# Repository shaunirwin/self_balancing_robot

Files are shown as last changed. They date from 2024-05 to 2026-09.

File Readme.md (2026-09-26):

# Self-balancing robot

Welcome to the project page for the self-balancing robot!

## Objectives

The goal of this project is to develop a robotic platform that can serve as a fun way to explore various aspects of robotics, including classical and learning-based control, 3D vision, sensor fusion and modelling.

## Status

The robot has been built and is currently using PID control for pitch control. Pitch estimation works well. I am busy simulating the system and improving the controller using classical control methods.

Once I am satisfied with the classical controller (both PID and LQR), I will move onto the next phase of learning-based control.

## Project layout

- [Firmware](firmware/platformio_projects/self_balancing_robot/README.md): ESP32 controller, HTTP API, and PC serial reader. Earlier ESP-IDF work is in `firmware/archived/`.
- [Laptop dashboard](software/webserver/README.md): live controls and recording viewer.
- [Python scripts and simulation](software/python/README.md): calibration, plotting, recording conversion, and MuJoCo model.
- [Electronics](electronics/robot_pcb/): KiCad PCB files; [cable harnesses](electronics/cable_harnesses/README.md) are alongside them.
- [Mechanical design](mechanical/Readme.md): Onshape CAD link and printing notes.
- [Recorded data](data/data_logs/README.md): logs and example recordings; older data is in `data/archive/`.
- [Documentation](documentation/): supporting figures.

The robot sitting in its harness:

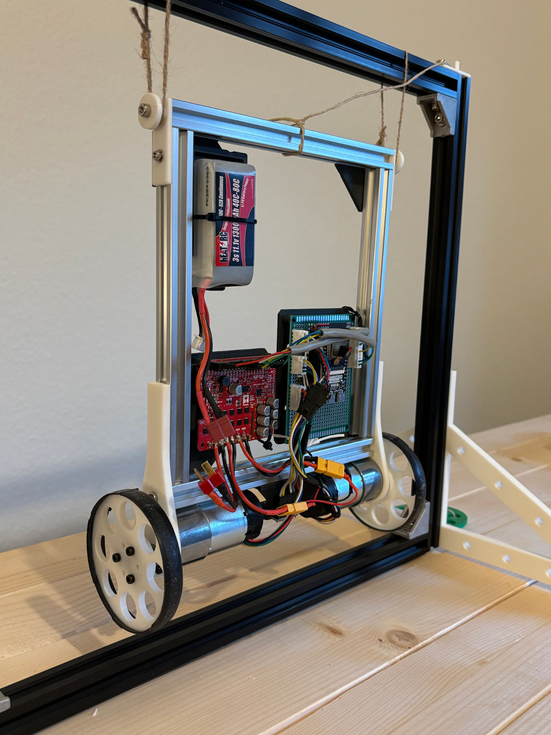
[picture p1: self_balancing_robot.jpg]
Self-balancing robot


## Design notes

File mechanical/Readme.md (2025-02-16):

# Readme

See [here](https://cad.onshape.com/documents/d3fc6fa172b94317767931eb/w/4836ae253482adeaddadde79/e/e547ee002620e145acb73cc3) for the OnShape design files.

I printed all components on a Bambu P1S using PLA.

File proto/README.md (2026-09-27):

# Recording format

`recording.proto` is the shared schema for robot recordings. An `SBRPB1` file
starts with the eight bytes `53 42 52 50 42 31 00 00` (`SBRPB1\0\0`). It is
followed by one varint-length-delimited `RecordingHeader`, then ordered
varint-length-delimited `RecordingBatch` messages until `record_count` samples
have been read. Each batch contains 1–16 samples, and its `first_index` must
equal the number of preceding samples. Files with trailing or missing data are
invalid. No wall-clock time is claimed; sample timestamps are monotonic and
relative to the recording start. Readers limit the header frame to 1024 bytes
and each batch frame to 2048 bytes. The file extension is `.sbrpb`.

The magic and `format_version` identify the framing and semantics. Additive
schema changes may use new field numbers without changing the major file
version. Never reuse a removed field number; mark it `reserved`. Change the
magic and major version if framing or existing field meanings change.

New recordings include `settings_at_start`, captured when the control task
processes Start. Older `SBRPB1` recordings omit it; readers should show
"metadata unavailable" for those and for `SBRLOG1` files. The original
header fields are retained for older protobuf readers. The snapshot holds PID
gains, output limits and integral threshold; pitch setpoint and safety limits;
complementary filter gyro weight; motor speed calibration slopes and intercepts,
direction inversion and coast settings; PWM frequency in Hz and resolution in
bits; wheel diameter in meters and encoder pulses per revolution; and IMU
offsets in radians per second (gyro Y) and radians (accelerometer pitch).
`imu_calibration_valid` is false if calibration had not finished at Start; in
that case the offset numbers are zero placeholders. `firmware_revision` is the
build Git revision, or `unknown` outside a Git checkout.

`settings_changed_during_recording` becomes true when an accepted live tuning
command actually changes a captured tunable value. It stays true if the value
is later restored. It does not track control mode or motor outputs, which are
stored per sample, or the completion of IMU calibration after Start. Thus a
false value means no captured tunable was changed by a command during this
recording; it does not turn the snapshot into a history of settings.

The robot keeps its 32-byte `SBRLOG1` records in RAM and encodes `SBRPB1` only
while downloading. `SBRLOG1` files remain readable by the dashboard and Python
decoder.

The firmware uses nanopb 0.4.9, Python uses generated `recording_pb2.py`, and
the Vite dashboard imports this `.proto` as text for protobuf.js. From the
repository root, run a PlatformIO build once to install nanopb, then regenerate
the checked-in C and Python files after editing the schema:

```sh
cd firmware/platformio_projects/self_balancing_robot
~/.platformio/penv/bin/pio run
cd ../../..
~/.platformio/penv/bin/python firmware/platformio_projects/self_balancing_robot/.pio/libdeps/esp32-s3-devkitc-1/Nanopb/generator/nanopb_generator.py -I proto -D firmware/platformio_projects/self_balancing_robot/src proto/recording.proto
~/.platformio/penv/bin/python -m grpc_tools.protoc -I proto --python_out=software/python proto/recording.proto
```

The dashboard reads the schema directly, so it has no generated file. Other
languages can generate readers from `recording.proto`; their file reader must
also implement the short framing described above.

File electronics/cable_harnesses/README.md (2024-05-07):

# README

This is the readme for cable harness-making.

## Setup

Install wireviz:

~~~
conda create -n wireviz_env python=3.10
conda activate wireviz_env
pip install wireviz

sudo apt-get install graphviz
~~~

## Generate cable harness diagrams

~~~
wireviz ~/path_to_file.yml
~~~

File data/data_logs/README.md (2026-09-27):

# README

This is the readme file for the data recordings in this folder. It describes what each was recorded for and when.

`balance-recording_11Hz_oscillation.bin`
* Created 2026-09-24
* Description: Recording of balancing attempt, where the robot exhibited a very pronounced ~11Hz oscillation on PID output, gyro, pitch, PWM. Robot falls over after a few seconds.
* Useful for: Debugging why the robot is not yet balancing correctly.

`balance-recording_gyros_noisy_motors_on.sbrpb`
* Created 2026-09-26
* Description: In this case the motors were on and the gyros were very noisy.
* Useful for: Investigating noisiness in the gyros. 

`balance-recording_gyros_smooth_motors_off.sbrpb`
* Created 2026-09-26
* Description: In this case the motors were off and the gyros were very smooth.
* Useful for: Investigating noisiness in the gyros.

`20260927-003031_recording_manual_step_motor1_to_35pwm.sbrpb`
* Description: Manual mode. Step input from zero pwm to 35. Gyro readings noisy despite feedback loop being off.
* Useful for: Investigating noisiness in the gyros.

`20260927-003253_recording_manual_step_motor1_to_150pwm.sbrpb`
* Description: Manual mode. Step input from zero pwm to 150. Gyro readings noisy despite feedback loop being off.
* Useful for: Investigating noisiness in the gyros.

`20260927-005004_recording_manual_step_motor2_to_35pwm.sbrpb`
* Description: Manual mode. Step input from zero pwm to 35. Gyro readings noisy despite feedback loop being off.
* Useful for: Investigating noisiness in the gyros.

`20260927-005226_recording_manual_step_motor2_to_150pwm.sbrpb`
* Description: Manual mode. Step input from zero pwm to 150. Gyro readings noisy despite feedback loop being off.
* Useful for: Investigating noisiness in the gyros.

`20260927-010502_recording_11hz_oscillation_auto_mode_150hz_sampling.sbrpb`
* Description: Recreated the same experiment as recorded in `balance-recording_11Hz_oscillation.bin`, which was previously done with 100Hz sampling rate. Still same 11Hz oscillation seen when using the 150Hz sampling rate.
* Useful for: Debugging balancing

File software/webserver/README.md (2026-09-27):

# Laptop dashboard

The current dashboard uses `index.html`, `main.js`, and Vite. Earlier control
interface experiments are kept in [`archive/`](archive/README.md).

Run from `software/webserver` with Node.js 20.19+ or 22.12+:

```sh
npm install
ROBOT_URL=http://192.168.178.55 npm run dev
```

Open <http://localhost:5173>. Set `ROBOT_URL` to the robot's HTTP origin on your network (no path or trailing slash). The default is `http://192.168.178.55`. Restart Vite after changing it. The server listens only on loopback. Browser API calls use `/api/*`; Vite forwards them to the robot with `/api` removed. The existing ESP32 endpoints are unchanged.

Open a local `SBRPB1` `.sbrpb` or legacy `SBRLOG1` `.bin` file in the recording viewer, or use Start, Stop, then Download & open. The new download uses the shared protobuf schema in `../../proto/recording.proto`. Click a chart or drag the timeline to inspect the corresponding pitch in the 3D view. Drag across a plot to zoom all charts to the same time range. Scroll over a plot to zoom around the pointer; Shift + scroll, middle-button drag, or the toolbar pans. Reset view restores the full recording. The view shows only pitch. With no recording selected, it follows live status polling. Controller values are submitted through `/set-value` as form fields; the dashboard rereads `/status` to confirm queued changes. Automatic mode may remain inactive if the robot's arm conditions are not met.

Expand **Recording settings** in the viewer for the snapshot captured at Start,
its firmware revision, IMU calibration validity, and the live tuning change
flag. Older recordings show "Metadata unavailable". Units and flag semantics
are documented in [`proto/README.md`](../../proto/README.md).

```sh
npm run build
```

The build checks and bundles the dashboard. For connected controls and recording, use `npm run dev` so the API proxy is active; opening `dist/index.html` directly does not provide a robot connection.

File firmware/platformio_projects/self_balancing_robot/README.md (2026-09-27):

# README

This is the README for the Self-Balancing Robot.

## Building the firmware and serial reader

From the repository root, change to the PlatformIO project directory:

```bash
cd firmware/platformio_projects/self_balancing_robot
```

The firmware includes `src/secrets.h` for Wi-Fi credentials. On a fresh
checkout, create it from the tracked template:

```bash
cp src/secrets_template.h src/secrets.h
```

Edit `src/secrets.h` and replace `REPLACE_WITH_YOUR_SSID` and
`REPLACE_WITH_YOUR_PASSWORD` with your network name and password. The project
ignores `secrets.h` so credentials stay out of commits. Keep the template's
variable names unchanged; `src/main.cpp` uses them to connect to Wi-Fi.

Build both the robot firmware and the PC serial reader:

```bash
make
```

The serial reader is written to `.pio/read_serial`.

To build only one component:

```bash
make firmware
make read_serial
```

The firmware can also be built directly with PlatformIO:

```bash
~/.platformio/penv/bin/pio run
```

## Programming the ESP32 board

Plug the USB cable into the **right** USB slot on the ESP32-S3 WROOM Freenove board to program it and to send/receive serial communication, as shown in [this video](https://www.youtube.com/watch?v=VZDCkARFCPk&ab_channel=Freenove).

From the PlatformIO project directory, build and upload the firmware with:

```bash
make upload
```

This uses `/dev/ttyACM0`, as configured in `platformio.ini`.

The equivalent direct PlatformIO command is:

```bash
~/.platformio/penv/bin/pio run --target upload
```

To open PlatformIO's serial monitor after uploading:

```bash
~/.platformio/penv/bin/pio device monitor
```

Press `Ctrl+C` to exit the monitor.

## To receive serial communication

In the terminal:

```bash
tio /dev/ttyACM0
```
Check that this is the correct comm port (see `platformio.ini`).

`Ctrl+t q` to quit.

Build and run the application that reads and displays data from the ESP32:

```bash
make run-reader
```

Close `tio` or PlatformIO's serial monitor first because only one application can use `/dev/ttyACM0` at a time. Press `Ctrl+C` to stop the reader.

## HTTP control and telemetry

The robot connects to the configured Wi-Fi network and serves HTTP on port 80. The examples below use the current robot address:

```bash
ROBOT=http://192.168.178.55
```

The root endpoint is a simple connectivity check:

```bash
curl "$ROBOT/"
```

Read the live controller state and safety flags:

```bash
curl -s "$ROBOT/status" | python3 -m json.tool
```

Important fields include `CONTROL_MODE`, `ESTIMATES_VALID`, `AUTO_ARM_ALLOWED`, `pitch_angle_current`, and the current PWM limits.

### Updating controller values

`/set-value` is a `POST` endpoint requiring `key` and `value` form fields. Changes are queued for the control task. Angle values are in radians; PWM values are integers from 0 to 255.

Examples:

```bash
# Select or disarm the controller mode
curl -X POST --data-urlencode 'key=CONTROL_MODE' \
  --data-urlencode 'value=MANUAL' "$ROBOT/set-value"

curl -X POST --data-urlencode 'key=CONTROL_MODE' \
  --data-urlencode 'value=AUTO' "$ROBOT/set-value"

# PID parameters and setpoint
curl -X POST --data-urlencode 'key=PID_Kp' \
  --data-urlencode 'value=18' "$ROBOT/set-value"
curl -X POST --data-urlencode 'key=PID_Ki' \
  --data-urlencode 'value=0' "$ROBOT/set-value"
curl -X POST --data-urlencode 'key=PID_Kd' \
  --data-urlencode 'value=0.4' "$ROBOT/set-value"
curl -X POST --data-urlencode 'key=PID_setpoint' \
  --data-urlencode 'value=0' "$ROBOT/set-value"

# Motor limits and pitch safety thresholds
curl -X POST --data-urlencode 'key=MOTOR_DUTY_CYCLE_MIN' \
  --data-urlencode 'value=35' "$ROBOT/set-value"
curl -X POST --data-urlencode 'key=MOTOR_DUTY_CYCLE_MAX' \
  --data-urlencode 'value=160' "$ROBOT/set-value"
curl -X POST --data-urlencode 'key=PITCH_ANGLE_ERROR_MAX' \
  --data-urlencode 'value=0.174533' "$ROBOT/set-value"  # 10 degrees
curl -X POST --data-urlencode 'key=PITCH_ANGLE_ERROR_MIN' \
  --data-urlencode 'value=0.003491' "$ROBOT/set-value"  # 0.2 degrees
```

Manual motor commands are available for bench testing with the wheels raised:

```bash
curl -X POST --data-urlencode 'key=MOTOR_1_DIR_MANUAL' \
  --data-urlencode 'value=FORWARD' "$ROBOT/set-value"
curl -X POST --data-urlencode 'key=MOTOR_2_DIR_MANUAL' \
  --data-urlencode 'value=FORWARD' "$ROBOT/set-value"
curl -X POST --data-urlencode 'key=MOTOR_1_DUTY_CYCLE_MANUAL' \
  --data-urlencode 'value=35' "$ROBOT/set-value"
curl -X POST --data-urlencode 'key=MOTOR_2_DUTY_CYCLE_MANUAL' \
  --data-urlencode 'value=35' "$ROBOT/set-value"
```

Emergency stop:

```bash
curl -X POST --data-urlencode 'key=EMERGENCY_STOP' \
  --data-urlencode 'value=1' "$ROBOT/set-value"
```

The network emergency stop is a software request and is not a substitute for a physical motor-power cutoff.

### Recording telemetry in RAM

The firmware stores up to 20 seconds of 150 Hz telemetry in a fixed 96 KB buffer. Each recording contains pitch, gyro rate, PID output, encoder positions, loop timing, PWM, directions, mode, and estimate-validity flags. Serial telemetry remains at 20 Hz on average.

Start a recording while the robot is still in MANUAL. The dashboard sends its local start time automatically. For HTTP clients, send `started_at` to name the protobuf download from the recording start time:

```bash
curl -X POST --data-urlencode "started_at=$(date +%Y%m%d-%H%M%S)" "$ROBOT/recording/start"
```

The resulting protobuf filename is `YYYYMMDD-HHMMSS_recording.sbrpb`. If `started_at` is omitted, the download keeps the generic `balance-recording.sbrpb` name. The ESP32 has no configured wall clock; the timestamp comes from the client that starts the recording.

Check its progress:

```bash
curl -s "$ROBOT/recording/status" | python3 -m json.tool
```

Stop it explicitly:

```bash
curl -X POST "$ROBOT/recording/stop"
```

The recording also stops when the buffer fills or AUTO disarms. Once the status reports `"state": "READY"`, download and decode it:

```bash
curl -OJ "$ROBOT/recording/download?format=protobuf"
../../../software/python/.venv/bin/python ../../../software/python/decode_recording.py YYYYMMDD-HHMMSS_recording.sbrpb
```

The decoder writes a CSV with the same base name as the downloaded recording, which can be plotted or inspected with standard tools. Python scripts can call `recording_reader.read_recording(path)` to read the protobuf metadata and samples directly. The schema is in `../../../proto/recording.proto`. The robot keeps fixed 32-byte records in RAM and encodes protobuf in small batches only during download. The old `/recording/download` endpoint still serves `SBRLOG1` `.bin` files, which the decoder and dashboard can still read. Only one completed recording is retained; starting a new recording overwrites the previous one. Recordings are held in volatile RAM and are lost if the ESP32 resets or loses power.

Protobuf headers also contain a settings snapshot taken when the control task
processes Start, the build Git revision (or `unknown`), and a flag that turns
true if a captured tunable is changed during recording. Calibration offsets
are marked invalid if IMU calibration had not finished at Start. Field units
and flag semantics are listed in `../../../proto/README.md`.

The old `/logs` endpoint is deprecated and returns an error; use the `/recording/*` endpoints instead.

For compatibility, `START_LOGGING` and `STOP_LOGGING` are also accepted as `/set-value` keys, but the dedicated recording endpoints are preferred.

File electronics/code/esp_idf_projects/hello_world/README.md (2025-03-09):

# Readme

# Initial set up of ESP-IDF

```
git clone
git submodule update --init --recursive
```

# Creating a new project using ESP-IDF

```bash
get_idf
idf.py create-project -p . <project_name>
idf.py set-target esp32-s3
idf.py menuconfig
```

# How to build this project

```bash
get_idf
idf.py build
idf.py flash
idf.py fullclean
```

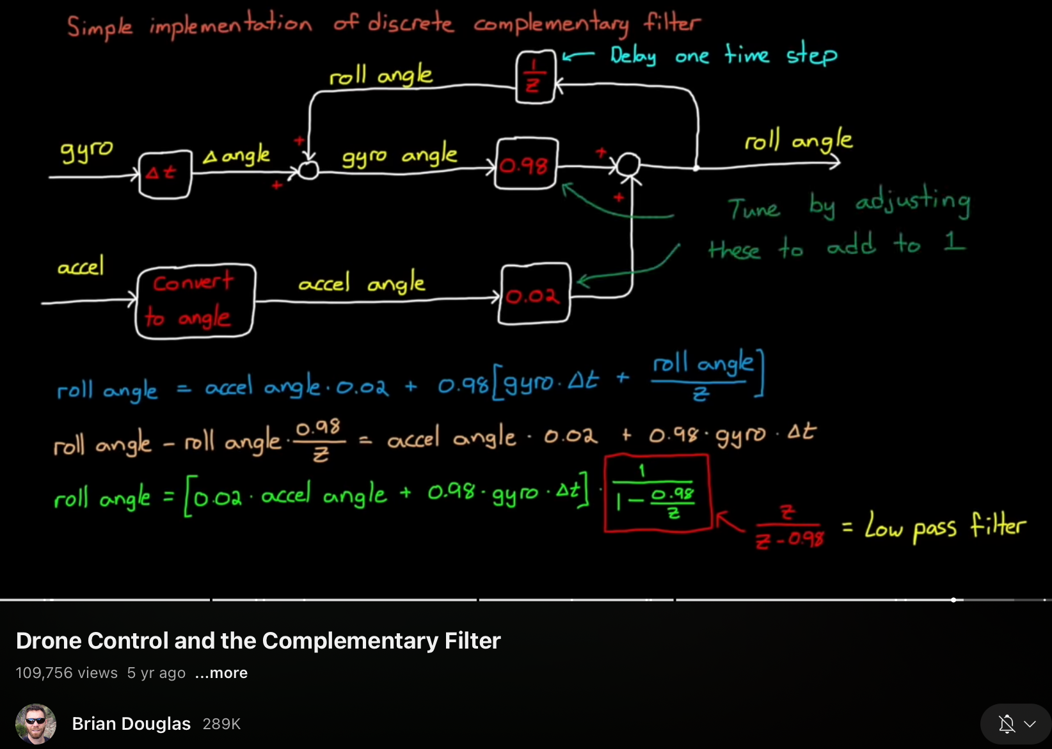
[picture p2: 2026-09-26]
documentation/complementary_filter.jpeg

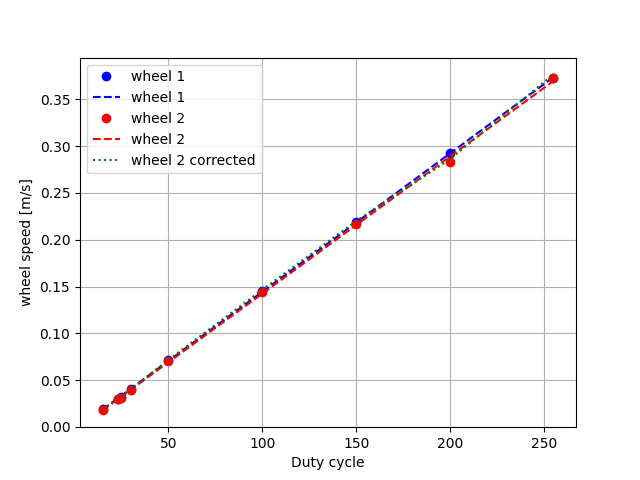
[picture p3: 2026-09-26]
software/python/pwm_calib.png

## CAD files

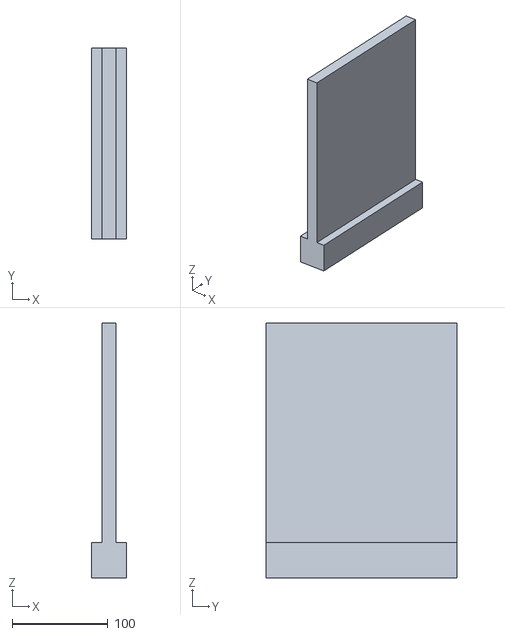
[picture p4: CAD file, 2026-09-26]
software/python/mujoco_simulation/body_v1.stl
37.0 x 200.0 x 267.0

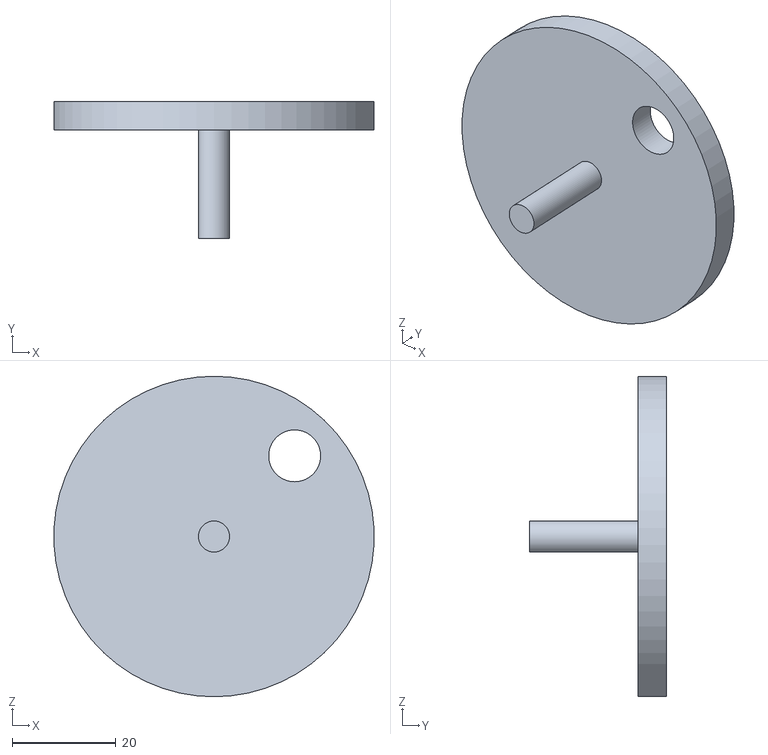
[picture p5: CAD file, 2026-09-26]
software/python/mujoco_simulation/wheel_L_v1.stl
61.7 x 26.5 x 61.8

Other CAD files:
software/python/mujoco_simulation/wheel_R_v1.stl

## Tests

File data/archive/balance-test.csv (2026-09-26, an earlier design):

elapsed_s | pitch_rad | pitch_deg | gyro_rad_s | gyro_deg_s | pid_output | motor1_encoder_pulses | motor2_encoder_pulses | control_interval_us | motor1_pwm | motor2_pwm | motor1_dir_pin | motor2_dir_pin | motor1_forward_command | motor2_forward_command | mode | estimates_valid
4294.967253 | -0.00066803 | -0.03828 | -0.01400511 | -0.80243 | 0.00000000 | 0 | 0 | 9978 | 0 | 0 | 1 | 0 | 1 | 1 | MANUAL | 1
0.009779 | -0.00070539 | -0.04042 | -0.01280669 | -0.73377 | 0.00000000 | 0 | 0 | 9822 | 0 | 0 | 1 | 0 | 1 | 1 | MANUAL | 1
0.019564 | -0.00060825 | -0.03485 | -0.00455089 | -0.26075 | 0.00000000 | 0 | 0 | 9785 | 0 | 0 | 1 | 0 | 1 | 1 | MANUAL | 1
0.029564 | -0.00044363 | -0.02542 | -0.00082246 | -0.04712 | 0.00000000 | 0 | 0 | 10000 | 0 | 0 | 1 | 0 | 1 | 1 | MANUAL | 1
0.039564 | -0.00021085 | -0.01208 | 0.01036281 | 0.59375 | 0.00000000 | 0 | 0 | 10000 | 0 | 0 | 1 | 0 | 1 | 1 | MANUAL | 1
0.049564 | -0.00005598 | -0.00321 | 0.00956386 | 0.54797 | 0.00000000 | 0 | 0 | 10000 | 0 | 0 | 1 | 0 | 1 | 1 | MANUAL | 1
0.059731 | -0.00001042 | -0.00060 | 0.01182755 | 0.67767 | 0.00000000 | 0 | 0 | 10167 | 0 | 0 | 1 | 0 | 1 | 1 | MANUAL | 1
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

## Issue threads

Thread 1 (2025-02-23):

Use ESP32 pcnt module to measure wheel position and speed

shaunirwin, 2025-02-23:
Currently interrupts are used to record quadrature encoder pulses from each motor, to determine angular position, direction and angular speed.

However, it would be more efficient to use the built in pcnt module on the ESP32. With the existing interrupt method there are either 700 or 1400 interrupts per revolution per wheel, which amounts to significant computational load that could be offloaded to hardware.

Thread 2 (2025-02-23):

Design a lag controller to reduce steady state wheel speed error

shaunirwin, 2025-02-23:
Try designing a lag controller and compare to the existing PI controller for wheel speed control. It would be good to reduce wheel speed steady state error while preventing the system becoming too slow to reach the setpoint, as is the case with the PI controller currently.

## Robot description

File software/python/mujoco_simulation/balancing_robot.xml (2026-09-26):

<mujoco model="simple_balancing_robot">
    <default>
        <!-- convert the Onshape coordinate system to MuJoCo -->
        <!--<geom type="mesh" xyaxes="1 0 0 0 0 1"/> -->
        <geom type="mesh" xyaxes="1 0 0 0 1 0"/>
    </default>

    <!-- Haze -->
    <visual>
        <headlight diffuse="0.6 0.6 0.6" ambient="0.1 0.1 0.1" specular="0 0 0" />
        <rgba haze="0.15 0.25 0.35 1" />
        <global azimuth="120" elevation="-20" />
    </visual>

    <asset>
        <!-- Onshape outputs meshes with mm units by default, but must be converted to m in MuJoCo, hence the scaling -->
        <mesh name="body" file="body_v1.stl" scale="0.001 0.001 0.001"/>
        <mesh name="wheelL" file="wheel_L_v1.stl" scale="0.001 0.001 0.001"/>
        <mesh name="wheelR" file="wheel_R_v1.stl" scale="0.001 0.001 0.001"/>

        <!-- Sky -->
        <texture type="skybox" builtin="gradient" rgb1="0.1 0.2 0.3" rgb2="0 0 0" width="512" height="3072" />
        <!-- Ground -->
        <texture type="2d" name="groundplane" builtin="checker" mark="edge" rgb1="0.3 0.4 0.5" rgb2="0.1 0.2 0.3" markrgb="0.8 0.8 0.8" width="300" height="300" />
        <material name="groundplane" texture="groundplane" texuniform="true" texrepeat="8 8" reflectance="0.2" />
    </asset>
    <worldbody>
        <light diffuse="0.5 0.5 0.5" pos="0 0 3" dir="0 0 -1"/>
        <geom name="floor" type="plane" size="0 0 0.05" pos="0 0 -0.031" group="1" material="groundplane" />
        <body name="body">
            <inertial pos="0.001 0.0 0.15" mass="0.9" diaginertia="0.001311 0.0012568 0.000487" />     <!-- offset slightly in front to break symmetry -->
            <geom mesh="body" rgba="0.8 0.1 0.1 1" />
            <joint name="joint_robot_body" type="free"/>
            <body name="wheelL">
                <inertial pos="0 0 0" mass="0.032" diaginertia="0.001311 0.0012568 0.000487"/>
                <geom mesh="wheelL" rgba="0.1 0.8 0.1 1"/>
                <joint name="joint_wheel_L" axis="0 1 0" type="hinge" damping="0.1"/>
            </body>
            <body name="wheelR">
                <inertial pos="0 0 0" mass="0.032" diaginertia="0.001311 0.0012568 0.000487"/>
                <geom mesh="wheelR" rgba="0.1 0.1 0.8 1"/>
                <joint name="joint_wheel_R" axis="0 1 0" type="hinge" damping="0.1"/>
            </body>
        </body>
    </worldbody>
    <actuator>
        <motor name="motor_L" joint="joint_wheel_L" />
        <motor name="motor_R" joint="joint_wheel_R" />
    </actuator>

    <option timestep="0.001" />
    <option gravity="0 0 -9.81" />

</mujoco>

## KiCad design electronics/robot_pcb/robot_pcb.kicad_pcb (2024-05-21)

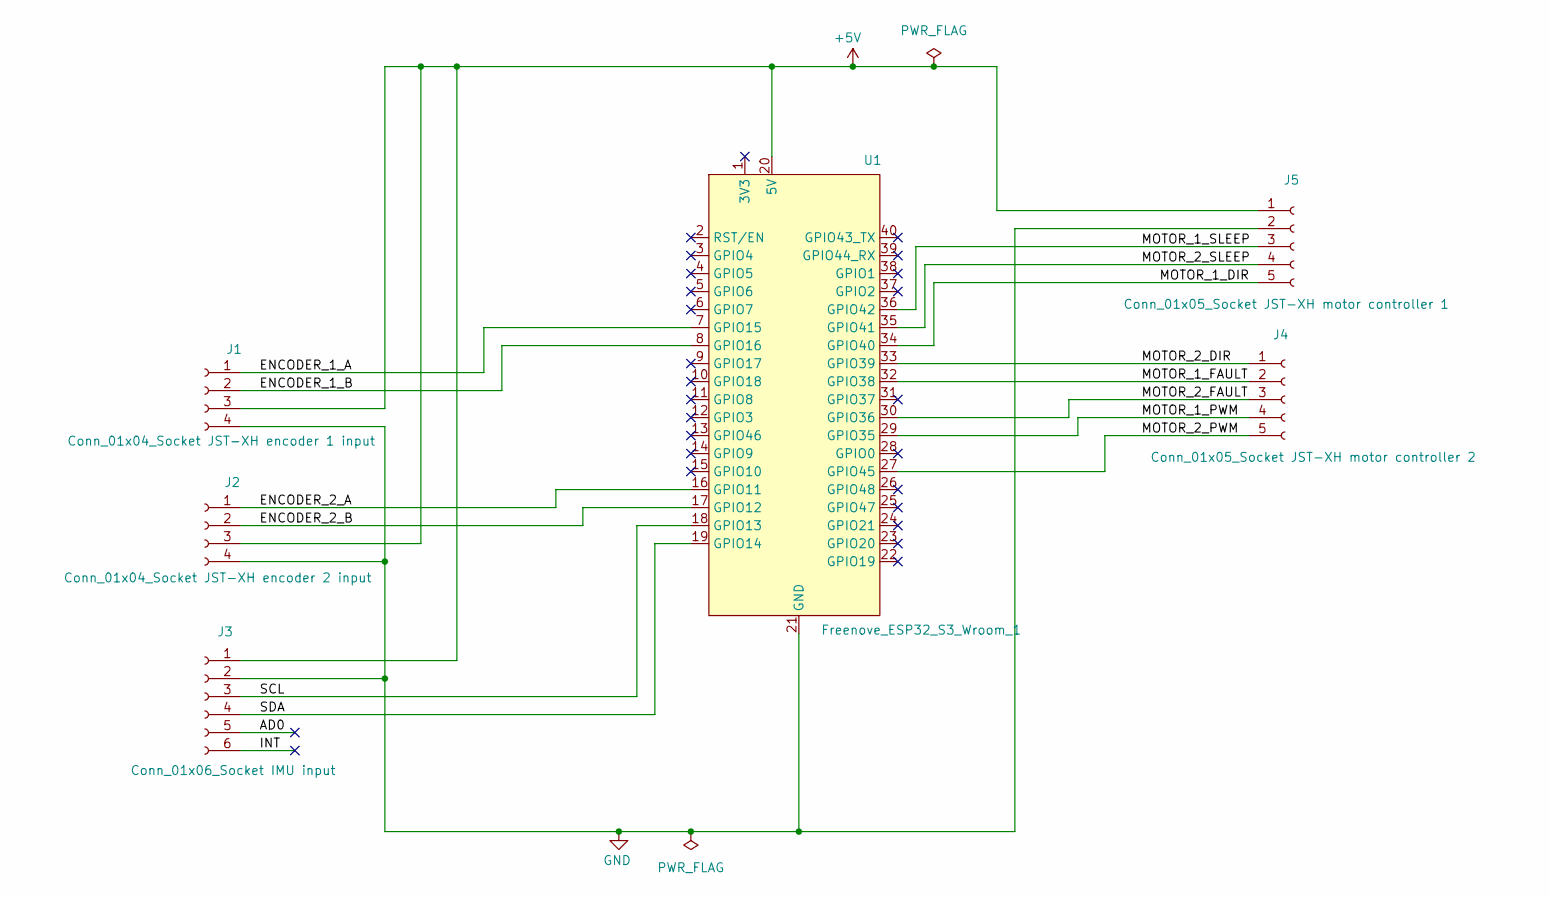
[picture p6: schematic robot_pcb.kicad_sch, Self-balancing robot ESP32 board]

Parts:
J1: Conn_01x04_Socket JST-XH encoder 1 input; PinSocket_1x04_P2.54mm_Vertical
J2: Conn_01x04_Socket JST-XH encoder 2 input; PinSocket_1x04_P2.54mm_Vertical
J3: Conn_01x06_Socket IMU input; PinSocket_1x06_P2.54mm_Vertical
J4: Conn_01x05_Socket JST-XH motor controller 2; PinSocket_1x05_P2.54mm_Vertical
J5: Conn_01x05_Socket JST-XH motor controller 1; PinSocket_1x05_P2.54mm_Vertical
U1: Freenove_ESP32_S3_Wroom_1; freenove_esp32_s3_wroom

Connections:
+5V: J1.3, J2.3, J3.1, J5.1, U1.20 (5V)
/AD0: J3.5
/ENCODER_1_A: J1.1, U1.7 (GPIO15)
/ENCODER_1_B: J1.2, U1.8 (GPIO16)
/ENCODER_2_A: J2.1, U1.16 (GPIO11)
/ENCODER_2_B: J2.2, U1.17 (GPIO12)
/INT: J3.6
/MOTOR_1_DIR: J5.5, U1.34 (GPIO40)
/MOTOR_1_FAULT: J4.2, U1.32 (GPIO38)
/MOTOR_1_PWM: J4.4, U1.29 (GPIO35)
/MOTOR_1_SLEEP: J5.3, U1.36 (GPIO42)
/MOTOR_2_DIR: J4.1, U1.33 (GPIO39)
/MOTOR_2_FAULT: J4.3, U1.30 (GPIO36)
/MOTOR_2_PWM: J4.5, U1.27 (GPIO45)
/MOTOR_2_SLEEP: J5.4, U1.35 (GPIO41)
/SCL: J3.3, U1.18 (GPIO13)
/SDA: J3.4, U1.19 (GPIO14)
GND: J1.4, J2.4, J3.2, J5.2, U1.21 (GND)

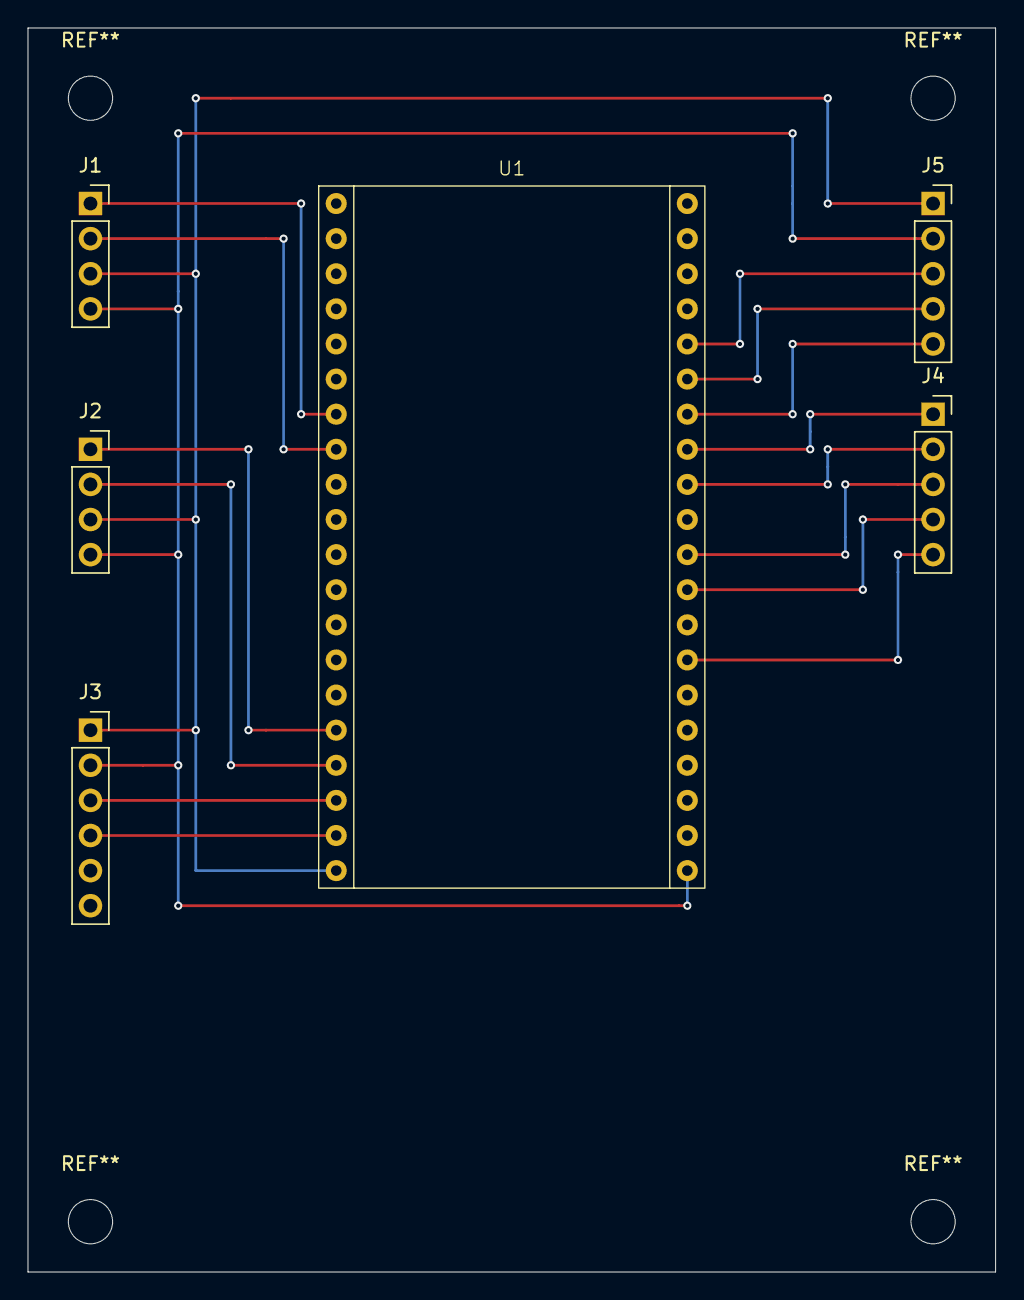
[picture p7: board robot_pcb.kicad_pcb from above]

Board: 2 copper layers, 70.0 x 90.0 mm, 6 parts (0 on the bottom side), 16 nets.

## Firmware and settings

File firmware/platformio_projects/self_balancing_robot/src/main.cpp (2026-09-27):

#include <iostream>
#include <string>
#include <algorithm>
#include <cstdint>
#include <atomic>
#include <cstring>
#include <array>
#include <memory>
#include <cmath>

#include <Arduino.h>
#include <WiFi.h>
#include <ESPAsyncWebServer.h>
#include <ArduinoJson.h>
#include <pb_encode.h>
#include "recording.pb.h"
#include "driver/pcnt.h"
// #include "driver/pulse_cnt.h"

// I2Cdev and MPU6050 must be installed as libraries, or else the .cpp/.h files
// for both classes must be in the include path of your project
#include "I2Cdev.h"
#include "MPU6050.h"

#include "data_structs.h"

// #include "sd_read_write.h"
// #include "SD_MMC.h"

// Arduino Wire library is required if I2Cdev I2CDEV_ARDUINO_WIRE implementation
// is used in I2Cdev.h
#if I2CDEV_IMPLEMENTATION == I2CDEV_ARDUINO_WIRE
    #include "Wire.h"
#endif

#include "secrets.h"
#include "pid.h"

MPU6050 imu;
AsyncWebServer server(80);

// // NB: it looks like these correspond to pin numbers, rather than GPIO numbers (therefore GPIOs 32, 33, 34)
// #define SD_MMC_CMD 38 //Please do not modify it.
// #define SD_MMC_CLK 39 //Please do not modify it. 
// #define SD_MMC_D0  40 //Please do not modify it.

const int PIN_LED_PWM = 2;
const int PIN_MOTOR1_SLEEP = 42;
const int PIN_MOTOR2_SLEEP = 41;
const int PIN_MOTOR1_DIR = 40;
const int PIN_MOTOR2_DIR = 39;
// Keep encoder numbering aligned with the corresponding motor/PWM channel.
const int PIN_ENCODER1A = 16;
const int PIN_ENCODER1B = 15;
const int PIN_ENCODER2A = 11;
const int PIN_ENCODER2B = 12;
const int PIN_MOTOR1_PWM = 35;
const int PIN_MOTOR2_PWM = 45;
const int PIN_I2C_SDA = 14;
const int PIN_I2C_SCL = 13;
// const int PIN_PULSE_INPUT = 11;   // testing PCNT module for wheel encoder position/speed measurement
const auto PCNT_UNIT = PCNT_UNIT_0;

const int PWM_FREQ = 30000;         // frequency to run PWM at [Hz]
const int MOTOR1_PWM_CHANNEL = 0;   // set the PWM channel
const int MOTOR2_PWM_CHANNEL = 1;   // set the PWM channel
const int PWM_RESOLUTION = 8;       // set PWM resolution

const bool MOTOR_1_DIR_INVERT = false;
const bool MOTOR_2_DIR_INVERT = true;
const bool MOTOR_COAST = false;
constexpr float MOTOR1_SPEED_SLOPE = 0.0014799539967724955f;
constexpr float MOTOR1_SPEED_INTERCEPT = -0.0036162999881075696f;
constexpr float MOTOR2_SPEED_SLOPE = 0.0014670524848993663f;
constexpr float MOTOR2_SPEED_INTERCEPT = -0.004342195129313476f;
#ifndef SBR_FIRMWARE_REVISION
#define SBR_FIRMWARE_REVISION "unknown"
#endif

bool ledStatus = true;

// state estimation
int16_t pcnt_encoder_pulse_count;  // for PCNT module
uint32_t intr_status;       // for PCNT module
volatile signed long motor1EncoderPulses = 0;
volatile int motor1DirMeas = 0;   // 0: stopped, 1: forward, -1: backward
volatile signed long motor2EncoderPulses = 0;
volatile int motor2DirMeas = 0;

long long packetID = 0;


float accel_resolution = 0;
float gyro_resolution = 0;
float pitchAngleGyro = 0;             // [rad]
float pitchAngleEst = 0;              // [rad]

// hardware timer
// Preserve the time constant of alpha=0.98 at 100 Hz.
const float ALPHA = std::pow(0.98f, 100.0f / ESTIMATOR_FREQ);
hw_timer_t *hwTimer = NULL;
volatile SemaphoreHandle_t timerSemaphore;
portMUX_TYPE timerMux = portMUX_INITIALIZER_UNLOCKED;
QueueHandle_t queueTelemetry;  // latest telemetry snapshot waiting for serial transmission
QueueHandle_t queueControlCommands;  // commands from the I/O core to the control core
std::atomic<bool> resetControlTimingRequested {false};
std::atomic<bool> emergencyStopRequested {false};

constexpr uint32_t TELEMETRY_RATE_HZ = 20;
static_assert(ESTIMATOR_FREQ >= TELEMETRY_RATE_HZ,
              "Telemetry rate must not exceed control rate");

// Keep the time-critical control pipeline away from Wi-Fi and web-server work.
constexpr BaseType_t IO_CORE = 0;
constexpr BaseType_t CONTROL_CORE = 1;
constexpr UBaseType_t IO_TASK_PRIORITY = 1;
constexpr UBaseType_t MOTOR_CONTROL_PRIORITY = 4;
constexpr float AUTO_ARM_MAX_PITCH_ERROR = 5.0f * M_PI / 180.0f;

enum class ControlCommandType : uint8_t {
  SET_PID_KP,
  SET_PID_KI,
  SET_PID_KD,
  SET_PID_SETPOINT,
  SET_DUTY_CYCLE_MIN,
  SET_DUTY_CYCLE_MAX,
  SET_PITCH_ERROR_MAX,
  SET_PITCH_ERROR_MIN,
  SET_CONTROL_MODE,
  SET_MOTOR1_DIRECTION,
  SET_MOTOR2_DIRECTION,
  SET_MOTOR1_DUTY,
  SET_MOTOR2_DUTY,
  START_RECORDING,
  STOP_RECORDING,
};

typedef struct {
  ControlCommandType type;
  float floatValue;
  uint32_t uintValue;
  ControlMode controlMode;
  MotorDirection motorDirection;
  char recordingStartedAt[16];  // YYYYMMDD-HHMMSS from the HTTP client
} ControlCommand_t;

typedef struct {
  PacketHeader_t header;
  DataPacket_t data;
} TelemetryPacket_t;

MotorDirection dirDrive { MotorDirection::FORWARD };
MotorDirection motor1DirManual { MotorDirection::FORWARD }; // motor 1 direction when in manual mode
MotorDirection motor2DirManual { MotorDirection::FORWARD };
uint8_t dutyCycle1Manual {0};             // motor 1 duty cycle when in manual mode
uint8_t dutyCycle2Manual {0};

// Always boot disarmed. AUTO must be selected explicitly after calibration and
// the live state estimate have been checked.
ControlMode controlMode {MANUAL};
uint DUTY_CYCLE_MIN = 35;
uint DUTY_CYCLE_MAX = 160;      // conservative limit for initial floor tests
float PITCH_ANGLE_ERROR_MAX = 10.f*M_PI/180.f;   // disarm AUTO after a fall begins
float PITCH_ANGLE_ERROR_MIN = 0.2f*M_PI/180.f;   // minimumpitch angle error before motors cut off

// PID variables
float pitch_angle_setpoint = 0; //-3.7*M_PI/180;  // desired pitch angle [rad]
float pitch_angle_current = 0;        // current pitch angle [rad]

// Fixed-size, control-task-owned telemetry recording. The buffer is frozen
// before the I/O core is allowed to stream it over HTTP.
enum class RecordingState : uint8_t {
  EMPTY,
  RECORDING,
  READY,
  DOWNLOADING,
};

typedef struct {
  uint32_t elapsed_us;
  float pitch_rad;
  float gyro_rad_s;
  float pid_output;
  int32_t motor1_encoder_pulses;
  int32_t motor2_encoder_pulses;
  uint32_t control_interval_us;
  uint8_t motor1_pwm;
  uint8_t motor2_pwm;
  uint8_t flags;
  uint8_t reserved;
} RecordingRecord_t;

static_assert(sizeof(RecordingRecord_t) == 32,
              "RecordingRecord_t file format changed");

typedef struct {
  char magic[8];
  uint16_t version;
  uint16_t header_size;
  uint16_t record_size;
  uint16_t sample_rate_hz;
  uint32_t record_count;
  uint32_t capacity;
  float pid_kp;
  float pid_ki;
  float pid_kd;
  float pitch_setpoint_rad;
  float pitch_error_min_rad;
  float pitch_error_max_rad;
  uint8_t duty_cycle_min;
  uint8_t duty_cycle_max;
  uint16_t flags;
  uint32_t reserved[3];
} RecordingFileHeader_t;

static_assert(sizeof(RecordingFileHeader_t) == 64,
              "RecordingFileHeader_t file format changed");

constexpr uint32_t RECORDING_DURATION_SECONDS = 20;
constexpr uint32_t RECORDING_CAPACITY =
    RECORDING_DURATION_SECONDS * ESTIMATOR_FREQ;
RecordingRecord_t recordingBuffer[RECORDING_CAPACITY];
RecordingFileHeader_t recordingHeader {};
std::atomic<RecordingState> recordingState {RecordingState::EMPTY};
std::atomic<uint32_t> recordingCount {0};
int64_t recordingStartTimeUs = 0;
bool recordingSawAuto = false;
char recordingStartedAt[16] = {};
sbr_recording_RecordingSettings recordingSettingsAtStart {};
bool recordingSettingsChanged = false;

struct IMUCalibrationSnapshot {
  bool valid;
  float gyroYOffsetRadS;
  float pitchAccelOffsetRad;
};
portMUX_TYPE imuCalibrationMux = portMUX_INITIALIZER_UNLOCKED;
IMUCalibrationSnapshot imuCalibrationSnapshot {};

constexpr uint8_t PROTO_RECORDING_MAGIC[8] = {'S', 'B', 'R', 'P', 'B', '1', 0, 0};
constexpr size_t PROTO_BATCH_SAMPLES = 16;
constexpr size_t PROTO_FRAME_BUFFER_BYTES = 1280;
static_assert(PROTO_FRAME_BUFFER_BYTES >= sbr_recording_RecordingBatch_size + 2,
              "Protobuf batch frame exceeds scratch buffer");
static_assert(sbr_recording_RecordingHeader_size <= 1024,
              "Protobuf header exceeds reader frame limit");

struct ProtoDownloadState {
  RecordingFileHeader_t header;
  sbr_recording_RecordingSettings settings;
  bool settingsChanged;
  uint32_t count;
  uint32_t nextIndex = 0;
  size_t magicOffset = 0;
  size_t frameSize = 0;
  size_t frameOffset = 0;
  bool headerEncoded = false;
  std::array<uint8_t, PROTO_FRAME_BUFFER_BYTES> frame {};
};

bool encodeNextProtoFrame(ProtoDownloadState &state) {
  pb_ostream_t stream = pb_ostream_from_buffer(state.frame.data(), state.frame.size());
  if (!state.headerEncoded) {
    sbr_recording_RecordingHeader header {};
    header.format_version = 1;
    header.sample_rate_hz = state.header.sample_rate_hz;
    header.record_count = state.count;
    header.capacity = state.header.capacity;
    header.pid_kp = state.header.pid_kp;
    header.pid_ki = state.header.pid_ki;
    header.pid_kd = state.header.pid_kd;
    header.pitch_setpoint_rad = state.header.pitch_setpoint_rad;
    header.pitch_error_min_rad = state.header.pitch_error_min_rad;
    header.pitch_error_max_rad = state.header.pitch_error_max_rad;
    header.duty_cycle_min = state.header.duty_cycle_min;
    header.duty_cycle_max = state.header.duty_cycle_max;
    header.has_settings_at_start = true;
    header.settings_at_start = state.settings;
    std::strncpy(header.firmware_revision, SBR_FIRMWARE_REVISION,
                 sizeof(header.firmware_revision) - 1);
    header.settings_changed_during_recording = state.settingsChanged;
    if (!pb_encode_ex(&stream, sbr_recording_RecordingHeader_fields,
                      &header, PB_ENCODE_DELIMITED)) return false;
    state.headerEncoded = true;
  } else {
    if (state.nextIndex >= state.count) return false;
    sbr_recording_RecordingBatch batch {};
    batch.first_index = state.nextIndex;
    batch.samples_count = std::min<size_t>(
        PROTO_BATCH_SAMPLES, state.count - state.nextIndex);
    for (size_t i = 0; i < batch.samples_count; ++i) {
      const RecordingRecord_t &source = recordingBuffer[state.nextIndex + i];
      batch.samples[i] = {
        source.elapsed_us, source.pitch_rad, source.gyro_rad_s,
        source.pid_output, source.motor1_encoder_pulses,
        source.motor2_encoder_pulses, source.control_interval_us,
        source.motor1_pwm, source.motor2_pwm,
        static_cast<bool>(source.flags & 1U),
        static_cast<bool>((source.flags >> 1) & 1U),
        static_cast<sbr_recording_RecordingSample_ControlMode>((source.flags >> 2) & 3U),
        static_cast<bool>((source.flags >> 4) & 1U),
        static_cast<bool>((source.flags >> 5) & 1U),
        static_cast<bool>((source.flags >> 6) & 1U),
      };
    }
    if (!pb_encode_ex(&stream, sbr_recording_RecordingBatch_fields,
                      &batch, PB_ENCODE_DELIMITED)) return false;
    state.nextIndex += batch.samples_count;
  }
  state.frameSize = stream.bytes_written;
  state.frameOffset = 0;
  return true;
}

// PID controller
PropIntDiff pid(-1.f, 1.f, 1.f);

typedef struct {
  float pidKp;
  float pidKi;
  float pidKd;
  float pitchSetpoint;
  float pitchCurrent;
  uint dutyCycleMin;
  uint dutyCycleMax;
  float pitchErrorMax;
  float pitchErrorMin;
  ControlMode controlMode;
  MotorDirection motor1Direction;
  MotorDirection motor2Direction;
  uint dutyCycle1Manual;
  uint dutyCycle2Manual;
  bool estimatesValid;
  bool autoArmAllowed;
} ControlStatusSnapshot_t;

portMUX_TYPE controlStatusMux = portMUX_INITIALIZER_UNLOCKED;
ControlStatusSnapshot_t controlStatusSnapshot {};



void IRAM_ATTR stateEstimatorTimer(){
  BaseType_t higherPriorityTaskWoken = pdFALSE;
  xSemaphoreGiveFromISR(timerSemaphore, &higherPriorityTaskWoken);
  if (higherPriorityTaskWoken == pdTRUE) {
    portYIELD_FROM_ISR();
  }
}

const char *recordingStateToStr(const RecordingState state) {
  switch (state) {
    case RecordingState::EMPTY: return "EMPTY";
    case RecordingState::RECORDING: return "RECORDING";
    case RecordingState::READY: return "READY";
    case RecordingState::DOWNLOADING: return "DOWNLOADING";
  }
  return "UNKNOWN";
}

bool validRecordingStartedAt(const String &value) {
  if (value.length() != 15 || value[8] != '-') return false;
  for (size_t i = 0; i < 15; ++i) {
    if (i != 8 && (value[i] < '0' || value[i] > '9')) return false;
  }
  const int month = value.substring(4, 6).toInt();
  const int day = value.substring(6, 8).toInt();
  const int hour = value.substring(9, 11).toInt();
  const int minute = value.substring(11, 13).toInt();
  const int second = value.substring(13, 15).toInt();
  return month >= 1 && month <= 12 && day >= 1 && day <= 31
      && hour <= 23 && minute <= 59 && second <= 59;
}

bool startRecording(const char *startedAt) {
  if (recordingState.load(std::memory_order_acquire)
      == RecordingState::DOWNLOADING) {
    return false;
  }

  std::memcpy(recordingHeader.magic, "SBRLOG1", 8);
  recordingHeader.version = 1;
  recordingHeader.header_size = sizeof(RecordingFileHeader_t);
  recordingHeader.record_size = sizeof(RecordingRecord_t);
  recordingHeader.sample_rate_hz = ESTIMATOR_FREQ;
  recordingHeader.record_count = 0;
  recordingHeader.capacity = RECORDING_CAPACITY;
  recordingHeader.pid_kp = pid.kp;
  recordingHeader.pid_ki = pid.ki;
  recordingHeader.pid_kd = pid.kd;
  recordingHeader.pitch_setpoint_rad = pitch_angle_setpoint;
  recordingHeader.pitch_error_min_rad = PITCH_ANGLE_ERROR_MIN;
  recordingHeader.pitch_error_max_rad = PITCH_ANGLE_ERROR_MAX;
  recordingHeader.duty_cycle_min = static_cast<uint8_t>(DUTY_CYCLE_MIN);
  recordingHeader.duty_cycle_max = static_cast<uint8_t>(DUTY_CYCLE_MAX);
  recordingHeader.flags = 0;
  std::memset(recordingHeader.reserved, 0, sizeof(recordingHeader.reserved));

  IMUCalibrationSnapshot calibration;
  portENTER_CRITICAL(&imuCalibrationMux);
  calibration = imuCalibrationSnapshot;
  portEXIT_CRITICAL(&imuCalibrationMux);
  recordingSettingsAtStart = {
    pid.kp, pid.ki, pid.kd, pid.MIN, pid.MAX, pid.ITermThreshold,
    pitch_angle_setpoint, PITCH_ANGLE_ERROR_MIN, PITCH_ANGLE_ERROR_MAX,
    AUTO_ARM_MAX_PITCH_ERROR, ALPHA, DUTY_CYCLE_MIN, DUTY_CYCLE_MAX,
    MOTOR1_SPEED_SLOPE, MOTOR1_SPEED_INTERCEPT,
    MOTOR2_SPEED_SLOPE, MOTOR2_SPEED_INTERCEPT,
    MOTOR_1_DIR_INVERT, MOTOR_2_DIR_INVERT, MOTOR_COAST,
    PWM_FREQ, PWM_RESOLUTION, WHEEL_DIAMETER,
    ENCODER_PULSES_PER_REVOLUTION, calibration.valid,
    calibration.valid ? calibration.gyroYOffsetRadS : 0.0f,
    calibration.valid ? calibration.pitchAccelOffsetRad : 0.0f,
  };
  recordingSettingsChanged = false;

  recordingCount.store(0, std::memory_order_relaxed);
  recordingStartTimeUs = esp_timer_get_time();
  std::memcpy(recordingStartedAt, startedAt, sizeof(recordingStartedAt));
  recordingSawAuto = false;
  recordingState.store(RecordingState::RECORDING, std::memory_order_release);
  return true;
}

void stopRecording() {
  if (recordingState.load(std::memory_order_acquire)
      != RecordingState::RECORDING) {
    return;
  }

  recordingHeader.record_count =
      recordingCount.load(std::memory_order_acquire);
  recordingState.store(RecordingState::READY, std::memory_order_release);
}

uint8_t correctMotor2DutyCycle(const uint8_t dutyCycle) {
  // correct motor 2's commanded duty cycle to ensure resultant speed is same as motor 1 when commanded to have the same duty cycle

  const float dutyCycleCorrected = ((MOTOR1_SPEED_SLOPE * dutyCycle + MOTOR1_SPEED_INTERCEPT)
      - MOTOR2_SPEED_INTERCEPT) / MOTOR2_SPEED_SLOPE;

  return static_cast<uint8_t>(std::max(std::min(std::round(dutyCycleCorrected), 255.f), 0.f));
}

PIDControlPacket_t calcPID(const float pitch_angle_current, const float pitch_velocity_gyro) {

  // Compute the PID output
  pid.calculate(pitch_angle_setpoint, pitch_angle_current, pitch_velocity_gyro);

  const float motorPerc = pid.Output;
  const MotorDirection motorDir = motorPerc < 0 ? MotorDirection::FORWARD : MotorDirection::REVERSE;

  const bool pitch_error_exceeded = abs(pitch_angle_current - pitch_angle_setpoint) >= PITCH_ANGLE_ERROR_MAX;
  const bool pitch_error_small = abs(pitch_angle_current - pitch_angle_setpoint) <= PITCH_ANGLE_ERROR_MIN;
  const bool motor_power_too_low = abs(motorPerc) < 0.05;
  const bool disable_motors = pitch_error_exceeded || pitch_error_small || motor_power_too_low;
  const uint8_t dutyCycle = disable_motors ? 0 : static_cast<uint8_t>(static_cast<float>(DUTY_CYCLE_MAX - DUTY_CYCLE_MIN) * abs(motorPerc) + static_cast<float>(DUTY_CYCLE_MIN));

  PIDControlPacket_t pidPacket {
    .pitch_setpoint = pitch_angle_setpoint,
    .pitch_current = pitch_angle_current,
    .pitch_error = pitch_angle_current - pitch_angle_setpoint,
    .motorSpeed = motorPerc,
    .motorDir = motorDir,
    .dutyCycle = dutyCycle
  };

  return pidPacket;
}


MotorOutput_t calcMotorOutput(const MotorDirection motor1dir, 
                              const MotorDirection motor2dir,
                              uint8_t dutyCycle1,
                              uint8_t dutyCycle2,
                              const bool estimatesValid) {
  // receive the motor commands and format them to the physical motors

  // invert direction to specific motors in case wires are switched
  bool motor1dirActual = motor1dir == MotorDirection::FORWARD;
  bool motor2dirActual = motor2dir == MotorDirection::FORWARD;
  if (MOTOR_1_DIR_INVERT) {
    motor1dirActual = !motor1dirActual;
  }
  if (MOTOR_2_DIR_INVERT) {
    motor2dirActual = !motor2dirActual;
  }

  // correct motor2's duty cycle to ensure motors spin at same speed when same duty cycle commanded
  uint8_t dutyCycle2Calibrated = correctMotor2DutyCycle(dutyCycle2);   // TODO: check that this is applied to correct motor

  if (!estimatesValid) {
    dutyCycle1 = 0;
    dutyCycle2Calibrated = 0;
  }

  MotorOutput_t motorOutput {
    .dutyCycle1 = dutyCycle1,
    .dutyCycle2 = dutyCycle2,
    .dutyCycle2Calibrated = dutyCycle2Calibrated,
    .motor1dir = motor1dirActual,
    .motor2dir = motor2dirActual
  };

  return motorOutput;
}

void stopMotors() {
  motor1DirManual = MotorDirection::FORWARD;
  motor2DirManual = MotorDirection::FORWARD;
  dutyCycle1Manual = 0;
  dutyCycle2Manual = 0;

  controlMode = ControlMode::MANUAL;
}
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
void loop() {

  // loopTask is pinned to the control core by the Arduino framework. Yield it
  // while all application work is performed by the dedicated tasks above.
  delay(1000);

  // digitalWrite(PIN_MOTOR1_DIR, true);
  // digitalWrite(PIN_MOTOR2_DIR, false);

  // // ledcWrite(MOTOR1_PWM_CHANNEL, 50);        // set the Duty cycle out of 255
  // auto  pwm = 100; //50*1;
  // uint pwmCalib = correctMotor2DutyCycle(pwm);
  // ledcWrite(MOTOR1_PWM_CHANNEL, pwm); //pwmCalib);
  // ledcWrite(MOTOR2_PWM_CHANNEL, pwm);
  // delay(2000);

  // ledcWrite(MOTOR2_PWM_CHANNEL, 0);
  // ledcWrite(MOTOR1_PWM_CHANNEL, 0);

  // delay(2000);

  // digitalWrite(PIN_MOTOR1_DIR, false);
  // digitalWrite(PIN_MOTOR2_DIR, false);
  // ledcWrite(MOTOR2_PWM_CHANNEL, 23);
  // ledcWrite(MOTOR1_PWM_CHANNEL, 23);

  // delay(2000);

  // ledcWrite(MOTOR2_PWM_CHANNEL, 0);
  // ledcWrite(MOTOR1_PWM_CHANNEL, 0);

  // delay(2000);

}

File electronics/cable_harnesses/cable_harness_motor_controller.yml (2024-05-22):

connectors:
  X1:
    type: IDC 2x20      # connector type C. Connects cable to the G2 motor board
    subtype: female
    pincount: 40
    pins: [2, 6, 15, 16, 18, 22, 29, 31, 32, 33]
    pinlabels: [5V, GND, MOTOR_1_SLEEP,  MOTOR_2_SLEEP, MOTOR_1_DIR, MOTOR_2_DIR, MOTOR_1_FAULT, MOTOR_2_FAULT, MOTOR_1_PWM, MOTOR_2_PWM]
  X2:
    type: JST-XH 5 pin    # connector type G1. Connects cable to the ESP32 board
    subtype: male
    pinlabels: [5V, GND, MOTOR_1_SLEEP,  MOTOR_2_SLEEP, MOTOR_1_DIR]
  X3:
    type: JST-XH 5 pin    # connector type G2. Connects cable to the ESP32 board
    subtype: male
    pinlabels: [MOTOR_2_DIR, MOTOR_1_FAULT, MOTOR_2_FAULT, MOTOR_1_PWM, MOTOR_2_PWM]
  X:                    # a fake connector as a hack, just to allow wireviz to connect wire bundles to one another without a connector in between
    style: simple
    autogenerate: true
    type: ""
    ignore_in_bom: true

cables:
  W1:       # cable harness 1a
    gauge: 0.25 mm2
    length: 0.2
    color_code: DIN
    wirecount: 10
    shield: false
  W2:       # cable harness 1b
    gauge: 0.25 mm2
    length: 0.2
    color_code: DIN
    wirecount: 5
    shield: false
  W3:       # cable harness 1c
    gauge: 0.25 mm2
    length: 0.2
    color_code: DIN
    wirecount: 5
    shield: false

connections:
  -
    - X1: [2, 6, 15, 16, 18]
    - W1: [1-5]
    - [X,X,X,X,X]             # fake connectors for the sake of wireviz
    - W2: [1-5]
    - X2: [1-5]
  -
    - X1: [22, 29, 31, 32, 33]
    - W1: [6-10]
    - [X,X,X,X,X]         # fake connectors for the sake of wireviz
    - W3: [1-5]
    - X3: [1-5]

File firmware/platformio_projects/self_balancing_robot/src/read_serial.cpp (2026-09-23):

#include <iostream>
#include <iomanip>
#include <fcntl.h>
#include <unistd.h>
#include <termios.h>
#include <cstring>
#include <cmath>
#include <fstream>
#include <vector>
#include <chrono>
#include <cerrno>
#include <poll.h>

#include "data_structs.h"

#define SERIAL_PORT "/dev/ttyACM0"  // Adjust this to your serial device
#define BAUDRATE B115200

const char* controlModeToString(const ControlMode mode) {
    switch (mode) {
        case ControlMode::AUTO:
            return "AUTO";
        case ControlMode::MANUAL:
            return "MANUAL";
        case ControlMode::FUNCTION:
            return "FUNCTION";
        default:
            return "UNKNOWN";
    }
}



// typedef struct {
//     StateEstimatePacket_t state;
//     Contr

// } __attribute__((packed)) LogPacket_t;


typedef struct {
    long long packetID;

    int64_t microSecondsSinceBoot;

    float pitch_est;    // estimated pitch angle [rad]

    float motor1EncoderPulsesPerSec;
    float motor2EncoderPulsesPerSec;

    uint8_t dutyCycle1;
    uint8_t dutyCycle2;

    uint32_t controlIntervalUs;
    float averageControlIntervalUs;
    float averageAbsControlJitterUs;
    uint32_t maxAbsControlJitterUs;

    std::string toCSVRow() const {
      std::stringstream csvRow;
      csvRow << packetID << "," << microSecondsSinceBoot / 1000 << std::fixed << std::setprecision(3) << "," << 
        pitch_est * 180./M_PI << "," << motor1EncoderPulsesPerSec << "," << motor2EncoderPulsesPerSec << "," << 
        static_cast<int>(dutyCycle1) << "," << static_cast<int>(dutyCycle2) << "," <<
        controlIntervalUs << "," << averageControlIntervalUs << "," <<
        averageAbsControlJitterUs << "," << maxAbsControlJitterUs << "\n";
      return csvRow.str();
    }

    std::string getCSVHeader() const {
      std::string csvHeader{ "packetID,timeMs,pitch_est deg,motor1EncoderPulsesPerSec,motor2EncoderPulsesPerSec,dutyCycle1,dutyCycle2,controlIntervalUs,averageControlIntervalUs,averageAbsControlJitterUs,maxAbsControlJitterUs\n" };
      return csvHeader;
    }

} CSVRow_t;


template<typename T>
void writeBinaryData(const std::string& csvPath, const std::vector<T>& logPackets) {
    std::ofstream file(csvPath, std::ios::binary | std::ios::app);
    
    if (!file) {
        std::cerr << "Error opening file!" << std::endl;
        return;
    }

    file.write(reinterpret_cast<const char*>(logPackets.data()), logPackets.size());
}


void writeCSVHeader(const std::string& csvPath, const std::vector<CSVRow_t>& csvRows) {
    std::ofstream file(csvPath);
    
    if (!file) {
        std::cerr << "Error opening file!" << std::endl;
        return;
    }

    file << csvRows[0].getCSVHeader();
}


void writeCSVRows(const std::string& csvPath, const std::vector<CSVRow_t>& csvRows) {
    std::ofstream file(csvPath, std::ios::app);      // append mode
    
    if (!file) {
        std::cerr << "Error opening file!" << std::endl;
        return;
    }

    for (const auto csvRow : csvRows) {
        file << csvRow.toCSVRow();
    }
}



int configureSerial(const char* port) {
    int fd = open(port, O_RDWR | O_NOCTTY | O_NONBLOCK);  // Open serial port
    if (fd == -1) {
        std::cerr << "Error opening " << port << ": " << std::strerror(errno) << std::endl;
        return -1;
    }

    struct termios tty;
    if (tcgetattr(fd, &tty) != 0) {
        std::cerr << "Error reading settings for " << port << ": "
                  << std::strerror(errno) << std::endl;
        close(fd);
        return -1;
    }

    // Disable all terminal input/output translations so arbitrary binary packet
    // bytes arrive unchanged.
    cfmakeraw(&tty);

    // Set baud rate
    cfsetispeed(&tty, BAUDRATE);
    cfsetospeed(&tty, BAUDRATE);

    tty.c_cflag &= ~(PARENB | CSTOPB | CSIZE | HUPCL);
    tty.c_cflag |= CS8 | CREAD | CLOCAL;

    tty.c_cc[VMIN] = 1;
    tty.c_cc[VTIME] = 0;

    // Apply the settings
    if (tcsetattr(fd, TCSANOW, &tty) != 0) {
        std::cerr << "Error configuring " << port << ": "
                  << std::strerror(errno) << std::endl;
        close(fd);
        return -1;
    }

    return fd;
}

int readSerial(int fd, bool logToCSV, std::string csvPath) {

    const uint HEADER_LENGTH = sizeof(PacketHeader_t);
    const uint DATA_LENGTH = sizeof(DataPacket_t);
    const auto PACKET_LENGTH = HEADER_LENGTH + DATA_LENGTH + 2;
    constexpr int TELEMETRY_TIMEOUT_MS = 5000;
    char buffer[PACKET_LENGTH];  // We expect "!<header packet><data packet>@"
    int index = 0;
    uint packetsReceived = 0;
    uint64_t bytesReceived = 0;
    auto lastValidPacketTime = std::chrono::steady_clock::now();

    int64_t microSecondsSinceBootPrevious = 0;
    int motor1PulsesPrevious = 0;
    int motor2PulsesPrevious = 0;

    // to be logged to CSV
    const auto samplesPerLog = 500;
    std::vector<IMUPacket_t> imuPackets;
    std::vector<CSVRow_t> csvRows;

    while (true) {
        pollfd serialPoll {
            .fd = fd,
            .events = POLLIN,
            .revents = 0,
        };
        const int pollResult = poll(&serialPoll, 1, TELEMETRY_TIMEOUT_MS);

        if (pollResult < 0) {
            if (errno == EINTR) {
                continue;
            }
            std::cerr << "Error waiting for serial data: " << std::strerror(errno) << std::endl;
            return 1;
        }

        if (pollResult == 0) {
            if (packetsReceived == 0) {
                std::cerr << "No data received from " << SERIAL_PORT << " within "
                          << TELEMETRY_TIMEOUT_MS / 1000 << " seconds. Check the USB connection, "
                          << "port name, firmware, and that no serial monitor is using the port."
                          << std::endl;
            } else {
                std::cerr << "Telemetry stopped: no serial data received for "
                          << TELEMETRY_TIMEOUT_MS / 1000 << " seconds." << std::endl;
            }
            return 1;
        }

        if (serialPoll.revents & (POLLERR | POLLHUP | POLLNVAL)) {
            std::cerr << "Serial connection to " << SERIAL_PORT << " was lost." << std::endl;
            return 1;
        }

        char c;
        int n = read(fd, &c, 1);  // Read one byte

        if (n < 0) {
            if (errno != EAGAIN && errno != EWOULDBLOCK) {
                std::cerr << "Error reading " << SERIAL_PORT << ": "
                          << std::strerror(errno) << std::endl;
                return 1;
            }
            continue;
        }
        if (n == 0) {
            continue;
        }
        bytesReceived++;
        
        if ((index == 0) && (c != STX)) {
            continue;
        }
        
        {
            buffer[index++] = c;
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

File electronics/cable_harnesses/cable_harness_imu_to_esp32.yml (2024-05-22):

connectors:
  X1:
    type: Header      # connector type H. Connects cable to the IMU
    subtype: female
    pinlabels: [VCC, GND, SCL, SDA, XDA, XCL, ADD, INT]
  X2:
    type: JST    # connector type L. Connects cable to the ESP32 board
    subtype: male
    pinlabels: [VCC, GND, SCL, SDA, ADD, INT]

cables:
  W1:       # cable harness 2
    gauge: 0.25 mm2
    length: 0.15
    color_code: DIN
    wirecount: 6
    shield: false

connections:
  -
    - X1: [1,2,3,4,7,8]
    - W1: [1-6]
    - X2: [1-6]

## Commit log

2024-05-07 Add arduino sketches
2024-05-07 Add example cable harness wireviz
2024-05-07 Add kicad files
    [robot_pcb.kicad_pcb, robot_pcb.kicad_sch]
2024-05-09 Add cable harness yaml files
    [cable_harness_motor_controller.yml, cable_harness_motor_encoders_to_esp32.yml]
2024-05-09 Add gitignore to cable harness folder
2024-05-09 Update connectors for motor controller board
    [cable_harness_motor_controller.yml]
2024-05-09 Connect motor driver board to ESP32 board using two JST connectors
    [cable_harness_motor_controller.yml]
2024-05-12 Finished ESP32 board schematic
    [robot_pcb.kicad_sch]
2024-05-12 Add interrupts to measure quadrature encoder position and direction
    [robot_pcb.kicad_sch]
2024-05-13 Motor encoder
2024-05-19 Read IMU values into correct units
    [main.cpp]
2024-05-19 Calculate pitch angle using raw accel readings, ignoring linear motion
2024-05-19 Add hardware timer at 250Hz
2024-05-19 Trigger FreeRTOS task at 250Hz using hardware timer
2024-05-19 Send raw IMU readings at 250Hz via serial
2024-05-19 Calculate gyro offset in python
2024-05-19 Add complementary filter
2024-05-19 Implement complementary filter on ESP32
2024-05-21 Update pin locations for easier perf board soldering
    [robot_pcb.kicad_pcb, robot_pcb.kicad_sch]
2024-05-22 Update cable harnesses
    [cable_harness_motor_controller.yml]
2024-05-23 Zero gyro. Invert acceleromater readings due to sensor upside down
    [main.cpp]
2024-05-23 Configure motor 2 pins
2024-05-24 Control motors using pitch estimate!
2024-07-10 Wheel encoders working and sending pulse counts to python. Direction not yet sending correctly
    [main.cpp]
2024-07-10 Send encoder pulses and convert to distance per wheel on python side
2024-07-11 Calculate and send velocity measurements from wheel encoders
2024-07-11 Fix wheel velocity measurements
    [main.cpp]
2024-07-12 Print choice of data received over serial
2024-07-12 PID Kp term working!
2024-07-12 Switch motor direction and enable motors
2024-07-12 Cut off motors if pid output too low or pitch error exceeded
    [main.cpp]
2024-07-13 Cut off motors if angle error really small
    [main.cpp]
2024-07-13 Adjust PID settings
2024-07-13 Add async web server that sets PID Kp term from post request
2024-07-13 Allow setting PID and other variables
2024-07-13 Update PID class when PID params change
2024-07-13 Add new PID classes that allow overriding derivative term with gyro readings
2024-07-13 Use doubles instead of floats in pid calcs
2024-07-13 Replace PID library to support D term input from raw gyro
    [main.cpp]
2024-07-13 Add manual motor control
2024-07-14 Prefill gui fields from robot current values
2024-07-14 Use radio buttons to show motor dir
2024-07-14 Use enums for motor direction and control mode
2024-07-14 Add emergency stop button to gui
2024-07-15 Display pitch angle current in gui
2024-07-15 Correct motor2 duty cycle to match motor 1 speed. Transmit serial every N packets
    [main.cpp]
2024-08-06 Use float instead of doubles in pid
2024-08-06 Lower state estimator freq to 200Hz
2025-02-01 Switch wheel encoder signals around for DFRobot motors
2025-02-01 Update estimator rate, wheel diameter
2025-02-01 Update pulses per rev for DFRobot motors
2025-02-04 Get wheel encoders working
2025-02-04 Plot wheel encoder speed
2025-02-06 Send gyro calib data over serial
2025-02-07 Set 1400 pulses per rev encoders
2025-02-07 Update wheel encoder calib values
2025-02-07 Calculate gyro offset using average
2025-02-07 Read temp. Separate structs for raw and processed IMU data
2025-02-07 Calibrate accel
2025-02-07 Send serial at 100Hz
2025-02-07 Log IMU values to binary file
2025-02-08 Turn off motors until IMU calibrated
2025-02-08 Zero pitch setpoint and change pwm ranges
2025-02-08 Prevent duplication of constants
    [data_structs.h, main.cpp, read_serial.cpp]
2025-02-08 Refactor motor control structs
2025-02-08 Refactor motor control task into functions
2025-02-08 Only calculate PID if needed
2025-02-08 Add function to step motors
2025-02-08 Fixes to writing CSVs
    [read_serial.cpp]
2025-02-16 Remove unused arduino code
2025-02-20 Simulate motor as first order linear ode
2025-02-20 Add pwm calib script
2025-02-24 Get LED to blink using ESP-IDF
2025-03-09 Fix header file types
    [data_structs.h]
2025-03-09 Send current time in header packet
2026-09-23 Use elapsed time in rate gyro readings
2026-09-23 Fix encoder pulses
2026-09-23 Add safety features
    - Web commands now cross from core 0 to the control task through a FreeRTOS queue.
    - AUTO only arms with valid estimates and pitch within ±5° of the setpoint.
    - Arming clears manual PWM and resets PID state.
    - Exceeding the configured tilt limit disarms to MANUAL.
    - Emergency stop is handled by the control task and overrides queued commands.
    - /status now safely reports ESTIMATES_VALID and AUTO_ARM_ALLOWED.
    - Angle endpoint validation now correctly uses radians.
    - Firmware and telemetry reader build cleanly.
    [main.cpp]
2026-09-24 Plot motor direction as pos/neg forward/backward
2026-09-26 Add ArduinoJson dep. Move data_structs.h to platformio include dir
2026-09-26 Remove arduino MPU6050 library
2026-09-26 Add mujoco files
    [balancing_robot.xml, body_v1.stl, wheel_L_v1.stl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]
2026-09-26 Add data recordings
    [balance-test.csv, freefall.csv, motorSpinUp.csv]
2026-09-26 Move webserver and python code to software folder
    [balancing_robot.xml, body_v1.stl, wheel_L_v1.stl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]
2026-09-26 Fix downloading of protobuf file issue
    [main.cpp]
2026-09-26 Change frequency of main loop from 100 -> 150Hz
